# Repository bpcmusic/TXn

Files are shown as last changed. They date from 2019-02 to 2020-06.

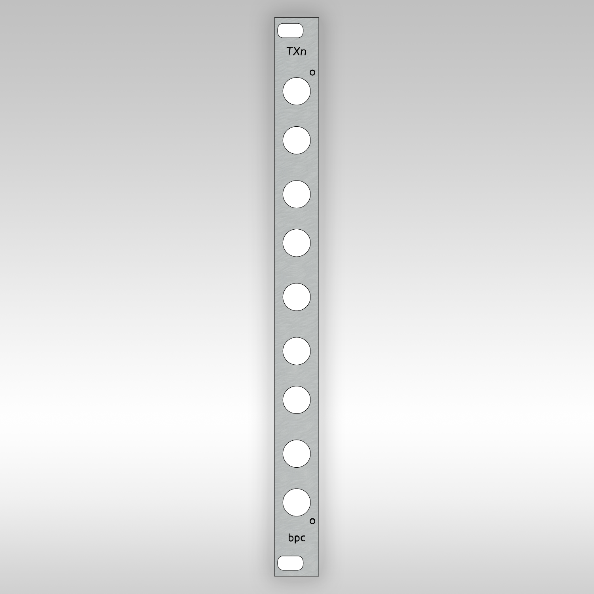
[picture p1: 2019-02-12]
panel/TXn_lg.png

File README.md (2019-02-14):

# TXn - Eurorack Fixed Panner/Mixer

The TELEXn (TXn) is a 2HP Remix of Jesper Särnesjö's open source module "nearness". Nearness is an ingenious module that you absolutely need in your rig. This remix compresses the original 3HP module into 2HP. You really can't go wrong with either one.

TXn

## What it Does

The module mixes and pans seven inputs to two outputs. There is an output at the top and bottom of the panel. Between these outputs are the seven inputs. These patch points correspond to panning positions between the two outputs. The closer you are to an output, the louder your signal will be there (and the quieter it will be in the corresponding output).

## How the TXn is Different from the 3HP Nearness

Again - all of the credit belongs with the original [Nearness Module](https://github.com/bpcmusic/nearness). The TXn is simply a reduced-form-factor version. A few changes needed to be made in order to accomplish this:

* The TXn is 1HP Smaller than Nearness (2HP vs 3HP).
* The TXn has a Power Section that is Different than the One on Nearness.
* The two boards on the TXn are oriented 90 degrees from each other (which can be tricky to solder).
* The TXn has a 1x5 power connector that hangs off the back of the module; its 6dB pad jumper connectors also hang off the back of the module.
* The TXn requires that the jacks be slightly raised off the top board in order to avoid electrical contact with the headers positioned underneath them. In fact, you will need to make sure you trim the headers flush with the top of the board priod to soldering. This is a real PITA, btw.

That's it.

If you are thinking you'd like to DIY a Nearness - it is highly recommended to consider building the 3HP version. It is much easier to solder and assemble.

## Module Specifications

* +12V: 25 mA  
* -12V: 26 mA  
* +5V: 0 mA  
* 2HP Width 
* 19mm Depth

## Folders & Files Explained

* **assistive**: 
	* ```TXn Build Guide.pdf``` - a PDF build guide to walk your through component-level placement
	* ```TXn Assembler.svg``` - little laser-cut forms to hold your boards together when soldering the 90 degree angle.
	* ```TXn Frame``` - a 3D printed frame to hold multiple TXn at a time
	* ```TXn Stencil Frame``` - a 3D printed stencil frame to hold the TXn in place while applying solder paste
	* ```TXn Stencil.svg``` - the solder paste stencil for laser cutting
	
* **board**
	* ```gerbers``` - the gerbers files (and Eagle files) for the top and bottom boards
	* ```images``` - image rederings of the boards
	* ```TXn_v1.2.brd/sch``` - the master Eagle file for the TXn
	
* **extras**
	* ```instructions.docx``` - the instructions delivered with the pre-built module
	* ```txn_mix_diagram.ai/svg``` - a digram of the module's mix behavior (used in the instructions file)
	
* **panel**
	* ```metalphoto``` - the individual files used for the creation of the metalphoto panel in the retail version
	* ```TXn.ai/svg``` - the panel files
	* ```TXn_lg.png``` - a big version of the panel
	* ```TXn_mp.zip``` - the archive sent for fabrication
	* ```TXn_sm.png``` - a small photo of the panel

* ```TXn BOM.csv``` - the BOM for this version of the TXb.

## Links

Nearness can be found in this repository:

* [Nearness Repository](https://github.com/bpcmusic/nearness)

Visit the TXn on Modular Grid:

* [Modular Grid](https://www.modulargrid.net/e/other-unknown-telexn)

Pre-built TXn are occasionally made availalbe for purchase here:

* [store.bpcmusic.com](https://store.bpcmusic.com/products/telexn?variant=5636075159583)

## License

[CC BY-SA 4.0](http://creativecommons.org/licenses/by-sa/4.0/)

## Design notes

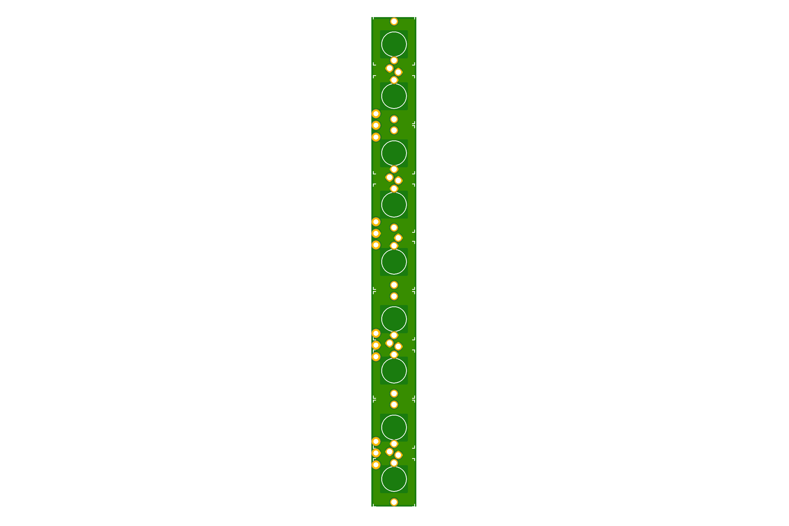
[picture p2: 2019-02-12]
board/images/TXn_v1.2_toponly.png

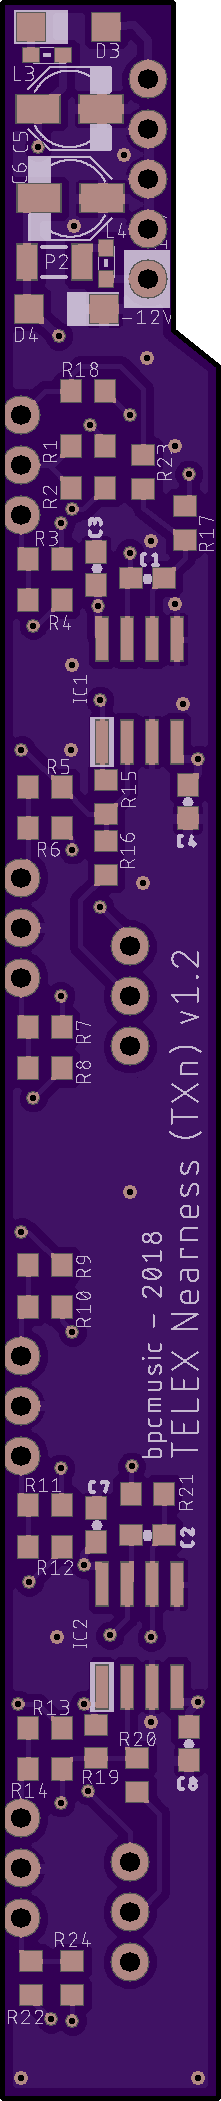
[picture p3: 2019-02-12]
board/images/TXn-top-1.2.png

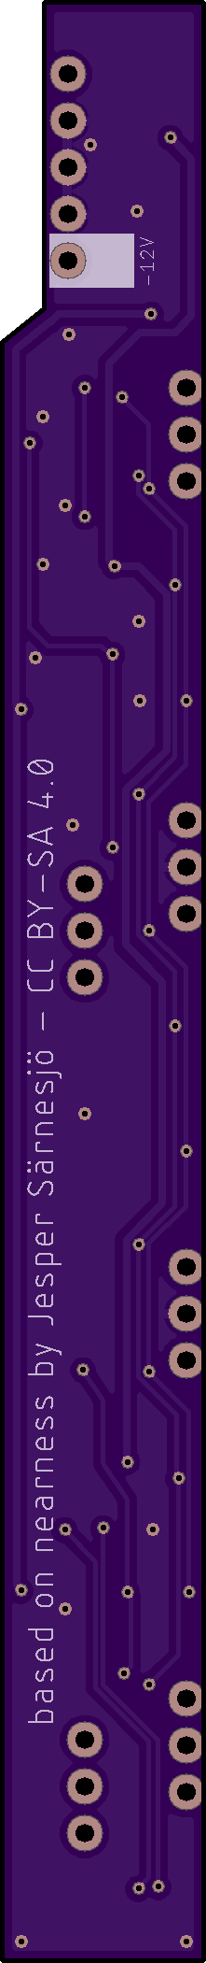
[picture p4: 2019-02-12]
board/images/TXn-bottom-1.2.png

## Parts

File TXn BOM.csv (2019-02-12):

Qty | Value | Package | Parts | Description | Mouser Part Number | Alternate Mouser Part | Notes
6 | 1X03 | 1X03 Angled | J1, J2, J3, J4, J5, J6, J7, J8, J9, J10 | Header | 538-22-28-8030
1 | 1X05 | 1X05 Angled | J11 | Header | 538-22-28-8050
2 | Diode | SOD123 | D3, D4 | Diode | 621-1N5819HW-F
10 | 100k | R0603 | R1, R14, R15, R16, R17, R19, R20, R21, R23, R24 | Resistor | 667-ERA-3AEB104V
4 | 100nF | 0603-CAP | C3, C4, C7, C8 | Capacitor | 581-06035C104JAT2A | 80-C0603X104J3R
2 | 102k | R0603 | R3, R12 | Resistor | 667-ERA-3AEB1023V |  | 103k Calculated
2 | 113k | R0603 | R5, R10 | Resistor | 71-TNPW0603113KBEEA
2 | 140k | R0603 | R7, R8 | Resistor | 603-RT0603DRD07140KL |  | 141k Calculated
2 | 1M69 | R0603 | R2, R13 | Resistor | 603-RC0603FR-071M69L |  | 1M67 Calculated; Thick Film :(
2 | 1k | R0603 | R18, R22 | Resistor | 66-WINT0603LF111001A | 652-CRT0603BY1001EAS
2 | 215k | R0603 | R6, R9 | Resistor | 667-ERA-3AEB2153V
2 | 22pF | 0603-CAP | C1, C2 | Capacitor | 80-C0603C220C5G
2 | 22uF | PANASONIC_B | C5, C6 | Polarized Capacitor | 667-EEE-FT1E220AR
2 | 442k | R0603 | R4, R11 | Resistor | 603-RT0603DRE07442KL |  | 439k Calculated
2 | 742792664 | 603 | L3, L4 | Ferrite Bead | 710-742792664
2 | LME49720 | SO08 | IC1, IC2 | OP AMP | 926-LME49720MAX/NOPB
1 | PTCSMD | PTC-1206 | P2 | Fuse PTC | 576-1206L035/16YR
9 | JACK | PJ301M | U1, U2, U3, U4, U5, U6, U7, U8, U9 | 3.5mm Jack

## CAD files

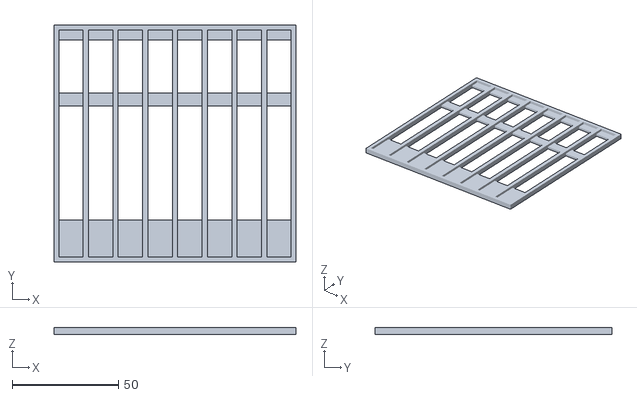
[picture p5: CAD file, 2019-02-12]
assistive/TXn Frame.stl
114.0 x 111.5 x 3.20

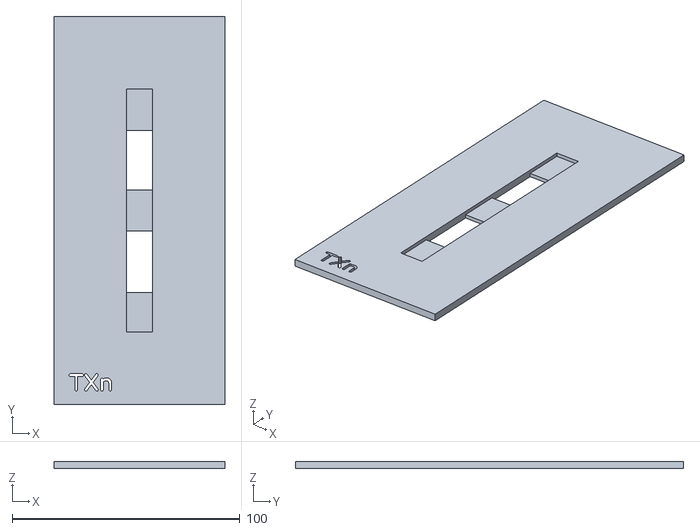
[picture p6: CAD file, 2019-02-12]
assistive/TXn Stencil Frame.stl
75.0 x 170.5 x 3.20

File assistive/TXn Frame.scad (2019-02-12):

$fn = 50;

// TXn Top

// framex = 250;


tolerance = .5;

pcbX = 11;
pcbY = 106.5;
pcbZ = 1.6;

frame = 2.5;

framex = pcbX + frame;

barOneStart = 0;
barOneEnd = 18;

barTwoStart = 71;
barTwoEnd = 77;

barThreeStart = 102;
barThreeEnd = 107.01 + (tolerance / 2);

corner = 2.5;

for (a =[0:7]) frame(a * (framex + .5));


module frame(xOrigin){

    union(){
        
        difference() {
            translate([xOrigin-frame, - frame, 0])
                cube([pcbX + 2 * frame, pcbY + 2 * frame, 2 * pcbZ]);
            translate([xOrigin-tolerance/2, -tolerance/2, 0])
                cube([pcbX + tolerance, pcbY + tolerance, 2 * pcbZ]);
        }

        translate([xOrigin-tolerance/2, barOneStart-(tolerance/2), 0])
            cube([pcbX + tolerance, barOneEnd - barOneStart -tolerance, pcbZ]);
            
        translate([xOrigin-tolerance/2, barTwoStart, 0])
            cube([pcbX + tolerance, barTwoEnd - barTwoStart, pcbZ]);
        
        translate([xOrigin-tolerance/2, barThreeStart, 0])
            cube([pcbX + tolerance, barThreeEnd - barThreeStart, pcbZ]);

    }
 
 }

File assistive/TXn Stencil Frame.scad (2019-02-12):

$fn = 50;

// TXo Bottom

tolerance = .5;

pcbX = 11;
pcbY = 106.5;
pcbZ = 1.6;

frame = 32;

barOneStart = 0;
barOneEnd = 18;

barTwoStart = pcbY / 2 - 9;
barTwoEnd = barTwoStart + 18;

barThreeStart = pcbY - 18;
barThreeEnd = 107.01 + (tolerance / 2);

corner = 2.5;

difference(){

    union(){
        difference() {
            translate([-frame, - frame, 0])
                cube([pcbX + 2 * frame, pcbY + 2 * frame, 2 * pcbZ]);
            translate([-tolerance/2, -tolerance/2, 0])
                cube([pcbX + tolerance, pcbY + tolerance, 2 * pcbZ]);
        }

        translate([-tolerance/2, barOneStart-(tolerance/2), 0])
            cube([pcbX + tolerance, barOneEnd - barOneStart -tolerance, pcbZ]);
            
        translate([-tolerance/2, barTwoStart, 0])
            cube([pcbX + tolerance, barTwoEnd - barTwoStart, pcbZ]);
        
        translate([-tolerance/2, barThreeStart, 0])
            cube([pcbX + tolerance, barThreeEnd - barThreeStart, pcbZ]);

    }

     translate([-frame * .8, -frame * .8]) {
       linear_extrude(height = 2 * pcbZ)
        text("TXn", font = "Core Humanist Sans:style=Bold", size = 8);
     }
 
 }

/*

translate([-13,-frame * .74,0])
    cube([10, pcbZ * .5, pcbZ / 3]);


translate([-4,-frame * .655,0])
    cube([8, pcbZ * .4, pcbZ / 3]);
 
translate([-4,-frame * .755,0])
    cube([7, pcbZ * .4, pcbZ / 3]);

translate([3,-frame * .74,0])
    cube([7, pcbZ * .4, pcbZ / 3]);
 
translate([18,-frame * .74,0])
    cube([7, pcbZ * .4, pcbZ / 3]);
 
 */               

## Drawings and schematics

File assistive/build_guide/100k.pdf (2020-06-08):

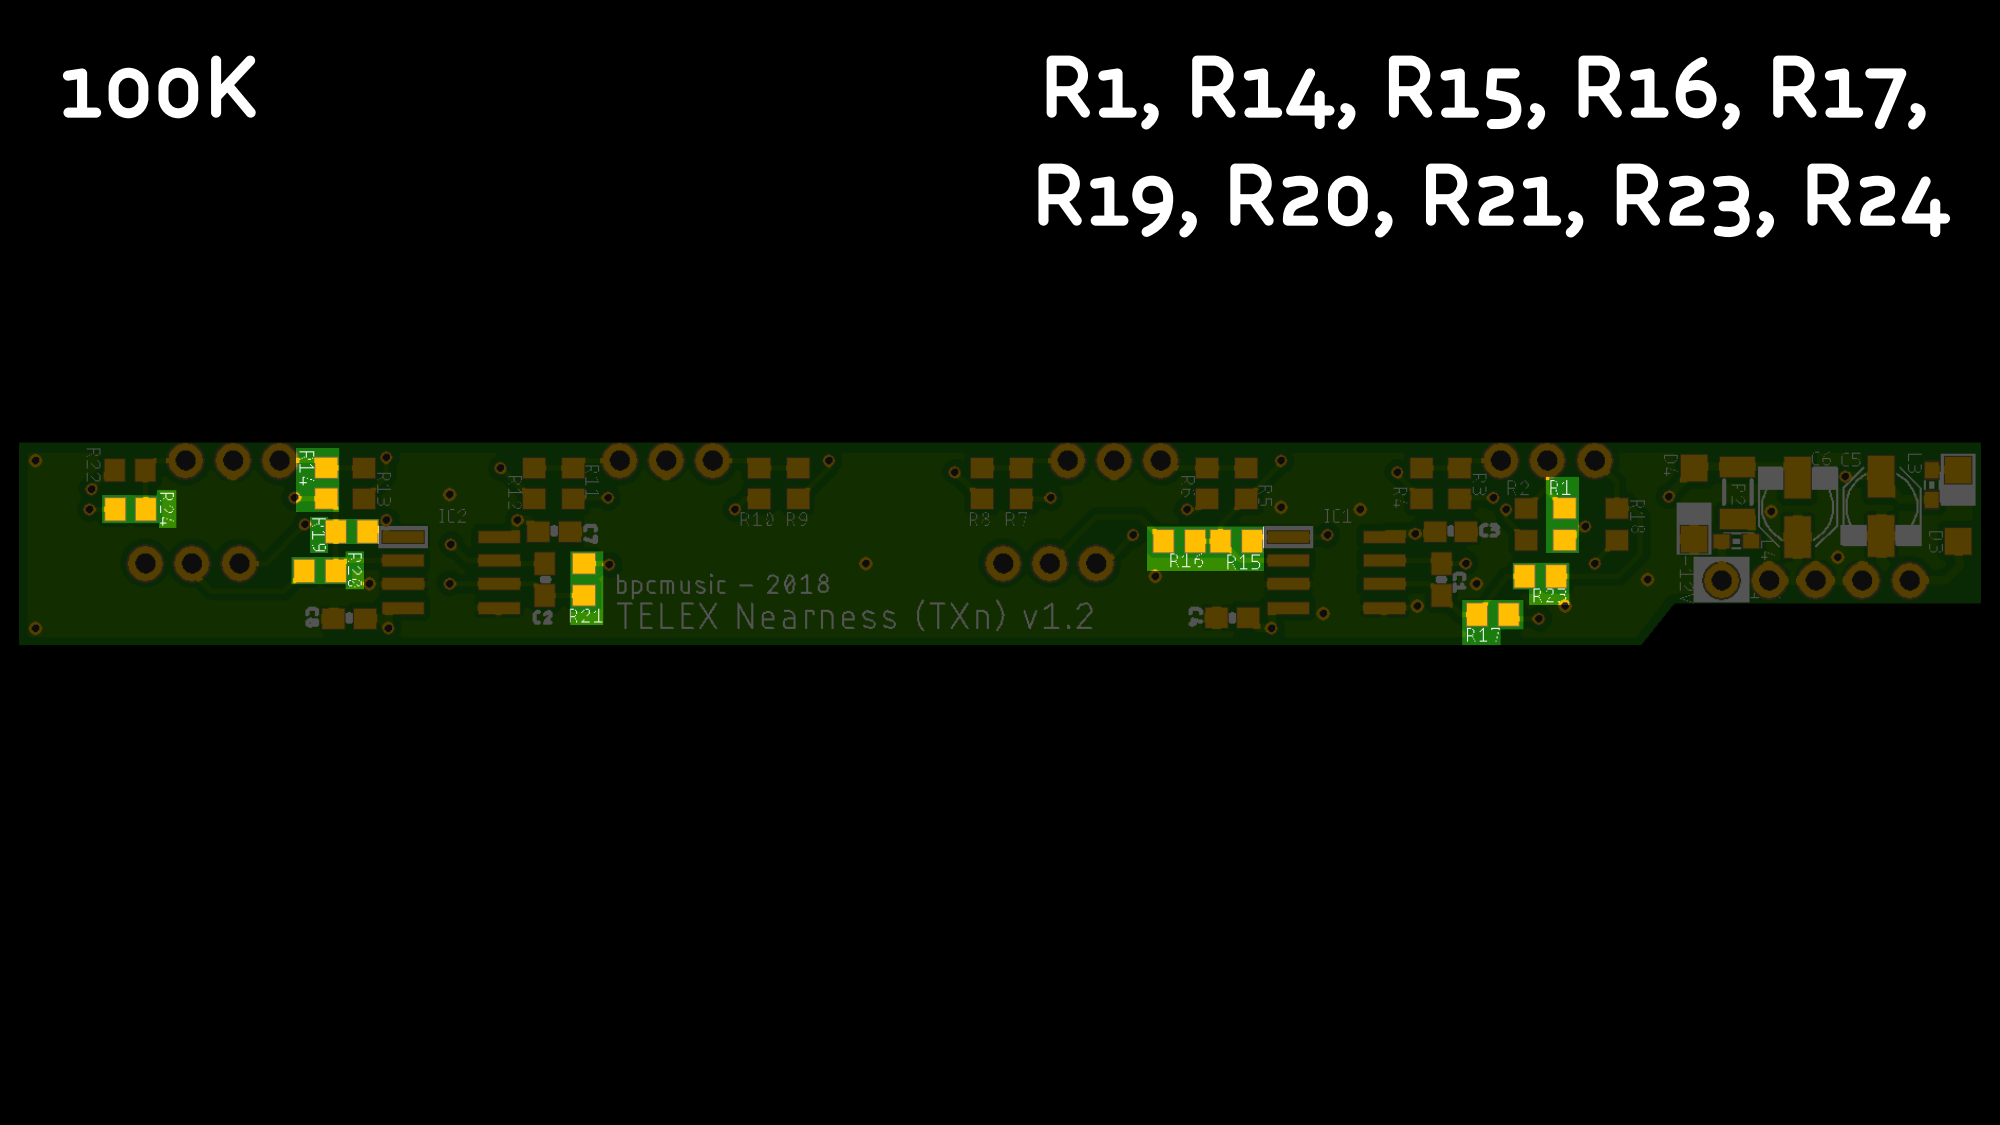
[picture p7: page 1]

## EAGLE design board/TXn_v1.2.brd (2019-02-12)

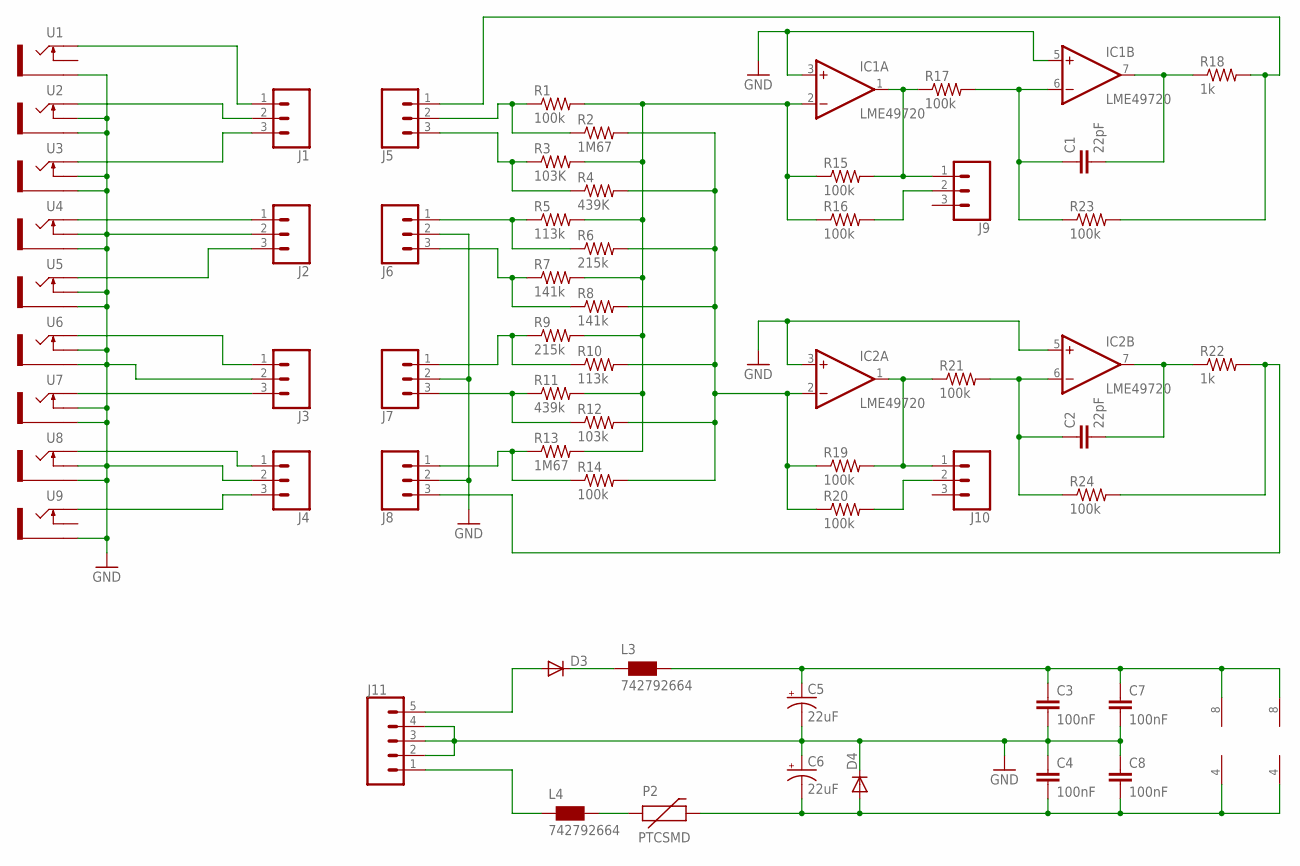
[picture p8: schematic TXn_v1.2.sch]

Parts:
C1, C2: 22pF; 0603-CAP
C3, C4, C7, C8: 100nF; 0603-CAP
C5, C6: 22uF; PANASONIC_B
D3, D4: DIODE-SOD123; SOD123
IC1, IC2: LME49720; SO08
J1, J2, J3, J4, J5, J6, J7, J8, J9, J10: CONN_031X03_NO_SILK; 1X03_NO_SILK
J11: CONN_05NO_SILK; 1X05_NO_SILK
L3, L4: 742792664; 0603
P2: PTCSMD; PTC-1206
R1, R14, R15, R16, R17, R19, R20, R21, R23, R24: 100k; R0603
R2, R13: 1M67; R0603
R3: 103K; R0603
R4: 439K; R0603
R5, R10: 113k; R0603
R6, R9: 215k; R0603
R7, R8: 141k; R0603
R11: 439k; R0603
R12: 103k; R0603
R18, R22: 1k; R0603
U1, U2, U3, U4, U5, U6, U7, U8, U9: THONKICONNLEFT; WQP-PJ301M-12_JACK_L

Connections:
BMIX: IC2.2 (-IN), R2.2, R4.2, R6.2, R8.2, R10.2, R12.2, R14.2, R19.1, R20.1
BOUT: J8.3, R22.2, R24.2
GND: C3.2, C4.1, C5.-, C6.+, C7.2, C8.1, D4.C, IC1.3 (+IN), IC1.5 (+IN), IC2.3 (+IN), IC2.5 (+IN), J2.2, J3.2, J4.2, J6.2, J7.2, J8.2, J11.2, J11.3, J11.4, U1.P$3_SLEEVE (SLEEVE), U2.P$2_SWITCH (SWITCH), U2.P$3_SLEEVE (SLEEVE), U3.P$2_SWITCH (SWITCH), U3.P$3_SLEEVE (SLEEVE), U4.P$2_SWITCH (SWITCH), U4.P$3_SLEEVE (SLEEVE), U5.P$2_SWITCH (SWITCH), U5.P$3_SLEEVE (SLEEVE), U6.P$2_SWITCH (SWITCH), U6.P$3_SLEEVE (SLEEVE), U7.P$2_SWITCH (SWITCH), U7.P$3_SLEEVE (SLEEVE), U8.P$2_SWITCH (SWITCH), U8.P$3_SLEEVE (SLEEVE), U9.P$3_SLEEVE (SLEEVE)
unnamed: J1.1, U1.P$1_TIP (TIP)
unnamed: J5.2, R1.1, R2.1
unnamed: J5.3, R3.1, R4.1
unnamed: J6.1, R5.1, R6.1
unnamed: J6.3, R7.1, R8.1
unnamed: J7.3, R11.1, R12.1
unnamed: J8.1, R13.1, R14.1
unnamed: J7.1, R9.1, R10.1
unnamed: J4.3, U9.P$1_TIP (TIP)
unnamed: J4.1, U8.P$1_TIP (TIP)
unnamed: J1.2, U2.P$1_TIP (TIP)
unnamed: J1.3, U3.P$1_TIP (TIP)
unnamed: J2.1, U4.P$1_TIP (TIP)
unnamed: J2.3, U5.P$1_TIP (TIP)
unnamed: J3.3, U7.P$1_TIP (TIP)
unnamed: IC2.1 (OUT), J10.1, R19.2, R21.1
unnamed: J3.1, U6.P$1_TIP (TIP)
unnamed: C2.1, IC2.6 (-IN), R21.2, R24.1
unnamed: IC1.1 (OUT), J9.1, R15.2, R17.1
unnamed: C1.1, IC1.6 (-IN), R17.2, R23.1
unnamed: C2.2, IC2.7 (OUT), R22.1
unnamed: J9.2, R16.2
unnamed: C1.2, IC1.7 (OUT), R18.1
unnamed: J10.2, R20.2
unnamed: D3.C, L3.1
unnamed: L4.2, P2.1
TMIX: IC1.2 (-IN), R1.2, R3.2, R5.2, R7.2, R9.2, R11.2, R13.2, R15.1, R16.1
TOUT: J5.1, R18.2, R23.2
VCC: C3.1, C5.+, C7.1, IC1.8 (V+), IC2.8 (V+), L3.2
VCC1: D3.A, J11.5
VEE: C4.2, C6.-, C8.2, D4.A, IC1.4 (V-), IC2.4 (V-), P2.2
VEE1: J11.1, L4.1

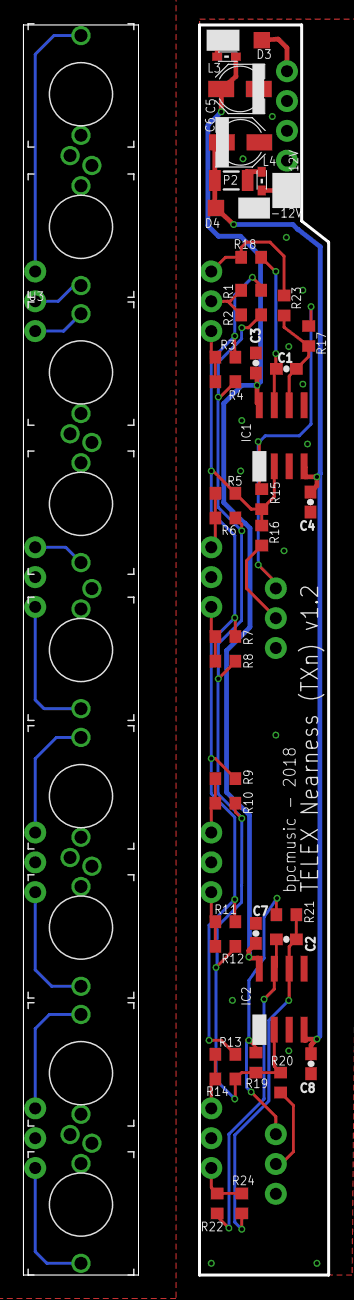
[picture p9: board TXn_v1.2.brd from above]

Board: 2 copper layers, 26.0 x 106.5 mm, 59 parts (0 on the bottom side), 35 nets.

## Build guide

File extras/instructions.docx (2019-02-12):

TELEXn TIPS

The TELEXn (TXn) is a seven-channel fixed panning mixer. It has two outputs, one at the top of the array of jacks and one at the bottom. Signals are panned between the two outputs based on the position of the jack. As you move out from the center, signals get louder in the nearest output and softer in the furthest. Got it? If not, here is a diagram that shows how it works:

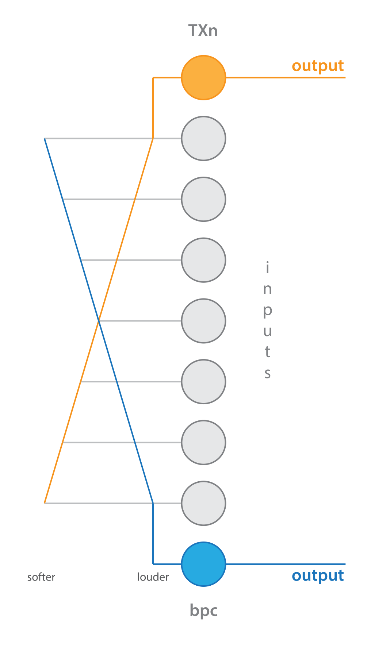
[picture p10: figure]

TELEXn TIPS

The TELEXn (TXn) is a seven-channel fixed panning mixer. It has two outputs, one at the top of the array of jacks and one at the bottom. Signals are panned between the two outputs based on the position of the jack. As you move out from the center, signals get louder in the nearest output and softer in the furthest. Got it? If not, here is a diagram that shows how it works:

The module uses standard Eurorack power. Make sure to orient your red stripe (-12V) properly. You can see it marked here on the close-up of the PCB:

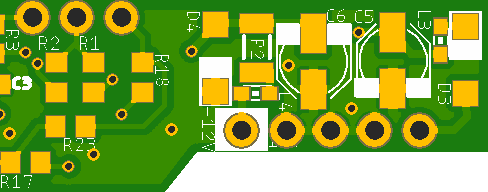
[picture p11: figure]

Finally, the TXn has two optional jumpers on the back where you can enable a 6dB pad for each of the channels. Simply use the included jumpers and connect the pins as marked below:

The TXn is based on the wonderful, minimal, open-source mixer Nearness designed by Jesper Särnesjö. This thing wouldn’t exist without all of the creativity and smarts he put into the original design. The TXn’s power section was inspired by designs from Mutable Instruments.

This module is also open source. All of the relevant files are available at https://github.com/bpcmusic/txn.

bpcmusic – 20181117; v1.0

The module uses standard Eurorack power. Make sure to orient your red stripe (-12V) properly. You can see it marked here on the close-up of the PCB:

Finally, the TXn has two optional jumpers on the back where you can enable a 6dB pad for each of the channels. Simply use the included jumpers and connect the pins as marked below:

The TXn is based on the wonderful, minimal, open-source mixer Nearness designed by Jesper Särnesjö. This thing wouldn’t exist without all of the creativity and smarts he put into the original design. The TXn’s power section was inspired by designs from Mutable Instruments.

This module is also open source. All of the relevant files are available at https://github.com/bpcmusic/txn.

bpcmusic – 20181117; v1.0

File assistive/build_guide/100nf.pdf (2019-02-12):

TXn 442K 215K 1KM6940K 113K02 22pf 100K | R1, R14, R15, R16, R17, R18, R22 R4, R11 R5, R10 R2, R13 R3, R12 D3, D4 R6, R978 C1, C2 R19, R20, R21, R23, R24
TXn LME49720 BEAD PTC Fuse DIODES 22uf | C3, C4, C7, C8 IC1, IC2 D3, D4 C5, C6 L3, L4F2

TXn

TXn Build Guide

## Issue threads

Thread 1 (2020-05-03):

Build guide errors

icedCreamEyes, 2020-05-03:
I recently built one of these and noticed that the orientation of R22 and R24 are incorrectly displayed in the assembly instruction images. Caught me out but was an easy correction.

Jagmills, 2020-05-16:
+1, just spotted the same mistake, after trying to work out why I wasn't getting output from one channel :)

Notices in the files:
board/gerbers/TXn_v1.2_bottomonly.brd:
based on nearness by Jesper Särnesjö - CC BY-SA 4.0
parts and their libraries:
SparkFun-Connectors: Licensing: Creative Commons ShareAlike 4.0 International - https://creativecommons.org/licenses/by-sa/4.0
